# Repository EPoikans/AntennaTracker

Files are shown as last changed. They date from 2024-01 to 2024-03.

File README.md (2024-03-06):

<h1>Antenna Tracker</h1>

Realtime GPS based antenna tracking ground station for your drone.

Raspberry Pi 4B is used for HDMI capture of Walksnail OSD and incoming Mavlink message reading via SiK radio to obtain realtime drone coordinates.
GPS coordinates are read from each OSD frame with OpenCV KNN algortihm.
It is possible to use either only Mavlink message reading, only OSD frame capturing and analyzing and both at the same time.

A Raspbbery Pi Pico is connected to the main computer (Raspberry Pi 4B or any other) and recieves realtime servo positions to track the drone with an optional GPS module for ground station coordinates



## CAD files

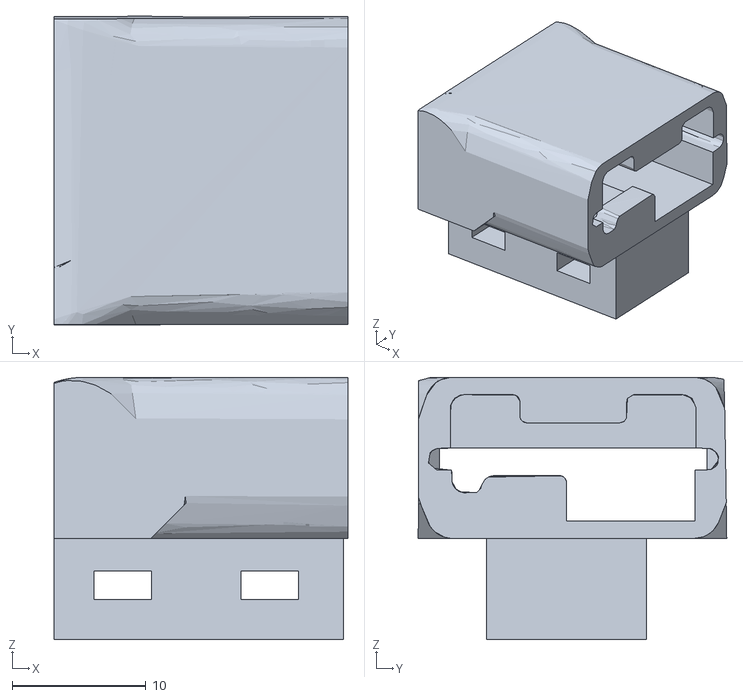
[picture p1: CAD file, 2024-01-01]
3D models/AntennaTracker_GPS_mount_TPU.stl
22.0 x 23.1 x 19.6

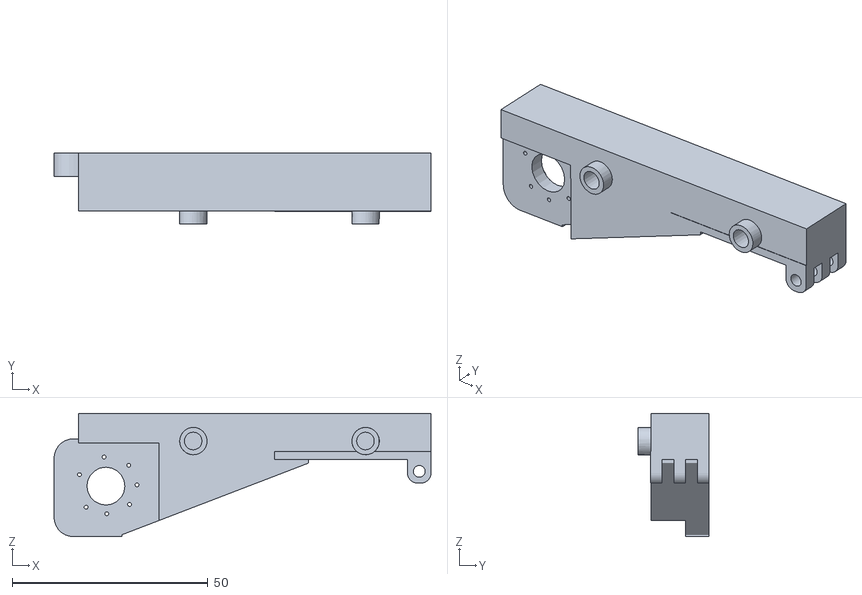
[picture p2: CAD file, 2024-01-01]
3D models/AntennaTracker_vertical_arm.stl
96.3 x 18.2 x 31.5

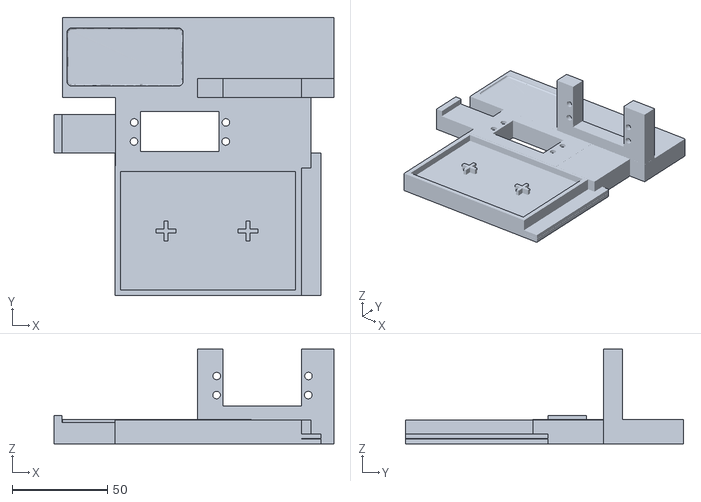
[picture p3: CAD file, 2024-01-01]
3D models/AntennaTracker_horizontal_plate.stl
146.9 x 145.9 x 49.7

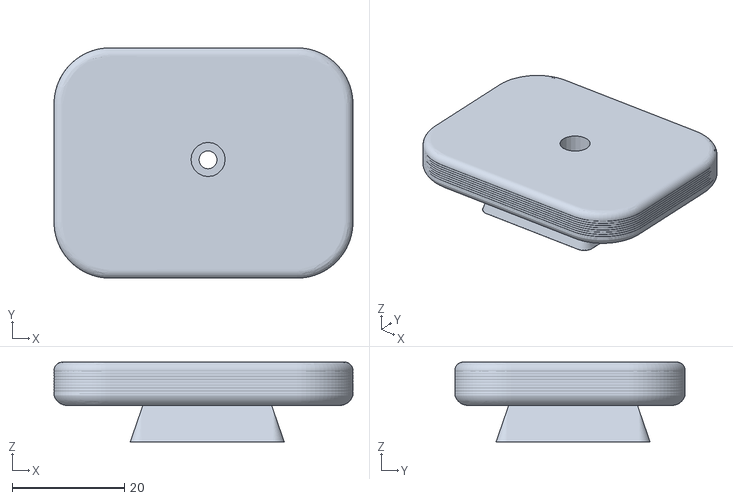
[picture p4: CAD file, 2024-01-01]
3D models/AntennaTracker_tripod_servo_connection.stl
53.4 x 41.1 x 14.2

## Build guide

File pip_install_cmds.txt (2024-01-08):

Windows cmds for required packages -
pip install pymavlink
pip install pyserial
pip install folium
pip install numpy
pip install opencv-python
pip install pillow

Raspberry pi commands for required packages - 
sudo pip install pymavlink --break-system-packages
sudo pip install pyserial --break-system-packages
sudo pip install folium --break-system-packages
sudo pip install numpy --break-system-packages
sudo pip install opencv-python --break-system-packages
sudo pip install pillow --break-system-packages

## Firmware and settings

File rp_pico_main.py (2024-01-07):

 
#Main script for the Raspberry Pi Pico. Does nothing on its own. 
#Communication over USB from serial_com.py file

from machine import Pin, I2C, UART, PWM
import sys
from time import sleep
import select
import utime
import ustruct
import math

compass_reg = { #QMC5883L magnetometer - https://datasheet.lcsc.com/lcsc/QST-QMC5883L-TR_C192585.pdf
    "MAGNETO_ADDRESS": 0xD,
    "MAGNETO_ID": 0xFF,
    "MAGNETO_ID_ADD": 0xD,
    "CONTROLREG1": 0x09,
    "CONTROLREG2": 0x0A,
    "DATAREG": 0x00,
    "DATACONV": 100.0 / 3000.0 #+/-8Gauss field range - 3000 LSb/Gauss -> 100LSb/uT
}

def initialize_pico(accelerometer = False):  
    global state, vertservo, horizonservo, i2c, uart_gps
    i2c = I2C(1, scl=Pin(19), sda=Pin(18), freq=400000) #I2C for magnetometer
    uart_gps = UART(0, baudrate=115200, tx=Pin(16), rx=Pin(17)) #UART for GPS
    
    if compass_reg["MAGNETO_ADDRESS"] in i2c.scan(): #Checks if magnetometer is connected
        i2c.writeto_mem(compass_reg["MAGNETO_ADDRESS"], compass_reg['CONTROLREG1'], bytes([0x1D]))
    vertservo = PWM(Pin(5)) #Vertical angle servo PWM pin
    horizonservo = PWM(Pin(6)) #Horizontal angle servo PWM pin
    vertservo.freq(50) #PWM frequency
    horizonservo.freq(50) #PWM frequency
    #Default servo states - 0deg vertical and horizontal with +/-115deg range
    vertservo.duty_u16(2000) #Vertical angle servo 2000-0deg, 5400 -90deg
    horizonservo.duty_u16(4900) # 4900 is center with roughly 115deg in each direction
    global vertservo, horizonservo, state
    state = True
    return state, vertservo, horizonservo

def readMagnetometer():
    global i2c
    try:
        data=i2c.readfrom_mem(compass_reg["MAGNETO_ADDRESS"], compass_reg["DATAREG"], 6)
        x = ((data[1] << 8) | data[0]) #Combines LSB and MSB in the correct order
        y = ((data[3] << 8) | data[2])
        z = ((data[5] << 8) | data[4])
        if x > 32767:
            x -= 65536
        if y > 32767:
            y -= 65536
        if z > 32767:
            z -= 65536
        x=(x)*compass_reg["DATACONV"] #Converts to uT
        #X axis offset due to servo motor magnetic field. Might need to be adjusted depending on location and servo
        x = x-136 
        y=(y)*compass_reg["DATACONV"] #Converts to uT
        #Y axis offset due to servo motor magnetic field. Might need to be adjusted depending on location and servo
        y = y - 50
        z=(z)*compass_reg["DATACONV"] #Converts to uT
        heading = math.atan2(y, x) #Calculates heading from magnetometer data
        heading = math.degrees(heading)
        day = 6
        declination_angle = math.sin(((-23.45)*math.pi/180) * math.cos(360/365 * (day + 10)))
        heading += declination_angle
        if heading < 0:
            heading += 360
        #print("Magnetic field in X: %.2f uT, Y: %.2f uT, Z: %.2f uT, Heading: %.2f°" % (x, y, z, heading)) #Debug print statement
        return str(heading)
    except:
        return ('err')

def setServoCycle (device, position): #Sets servo PWM cycle

    device.duty_u16(position)

    sleep(0.01)

def exec_cmd(command): #Processes incoming messages over USB to apropriate functions
    if(len(command)==0):
        return
    cmdparts = command.split() #Splits message into parts
    global vertservo, horizonservo, state
    fnname = cmdparts[0] #First part of message is the function name
    if(len(cmdparts) >=3 and cmdparts[0] == "setServoCycle"): #Checks if servo PWM cycle is being set
        servoname = cmdparts[1]
        pwmint = int(cmdparts[2])
    if fnname == "setServoCycle": #Sets servo PWM cycle
        if(servoname == "vert_servo"):
            setServoCycle(vertservo, pwmint)
            return("Set vert servo") #Returns a message to confirm the servo has been set
        elif(servoname == "horizon_servo"):
            setServoCycle(horizonservo, pwmint)
            return("Set horizontal servo") #Returns a message to confirm the servo has been set
    elif fnname == "initialize_pico": #Initializes the pico
        if(len(cmdparts)>=2 and cmdparts[1] == "accelerometer"):
            state, vertservo, horizonservo = initialize_pico(False) #True if use adxl345 - retired currently
        else:
            state, vertservo, horizonservo = initialize_pico()
        if(state):
            return("Initialized") #Returns a message to confirm the pico has been initialized
    elif fnname == "readMagnetometer": #Reads magnetometer data
        heading = readMagnetometer()
        return heading
    elif fnname == "pollGPS": #Requests GPS data from GPS module
        try:
            lat, lon = pollGPS()
            return lat, lon
        except:
            return 0, 0
    elif fnname == "checkGPSSat": #Requests active satellite count from GPS module
        sat_count = checkGPSSat()
        return sat_count
    elif fnname == "PortCheck": #PortCheck is sent to every possible serial port to find the correct one which the pico is connected to
        portconfirm = "RPPico" #Returns a message to confirm the pico has been found
        return str(portconfirm)

#GPS module chip - M10 using NMEA 0183 messages
"""
NMEA 0183 messages

Talker IDs -
BD or GB - Beidou
GA - Galileo
GP - GPS
GL - GLONASS
GN - Combined talkers

$(Talker ID) + GGA  - Global Positioning System Fixed Data
$(Talker ID) + GLL - Geographic Position-- Latitude and Longitude 
$(Talker ID) + GSA - GNSS Dilution of Precision and active satellites 
$(Talker ID) + GSV - GNSS satellites in view 
$(Talker ID) + RMC - Recommended minimum specific GPS data 
$(Talker ID) + VTG - Course over ground and ground speed 

<CR><LF> or \r\n - end of message
$ - begining of message

$GNGSA - active sattelite count
$GNGLL - lat and lon 
"""


def pollGPS():
    global uart_gps
    lat, lon, lat_deg, lat_min, lon_deg, lon_min = 0,0,0,0,0,0
    timeoutvar = 0
    while True:
        gps_data = uart_gps.readline() #Reads GPS data from UART
        if(gps_data != 'None'): #Checks if data is None or a NMEA message
            try:    
                gps_fields = gps_data.decode().split(',') #NMEA messages are split with ,
                if(gps_fields[0] == '$GNGLL' and gps_fields[6] == 'A'): #Latitude and Longitude with active satellites
                    lat_deg = gps_fields[1][:2]
                    lat_min = gps_fields[1][2:]
                    lon_deg = gps_fields[3][:3]
                    lon_min = gps_fields[3][3:]
                    lat = round((float(lat_deg) + (float(lat_min)/60)), 7) #Converts latitude and longitude from minutes to decimal
                    lon = round((float(lon_deg) + (float(lon_min)/60)), 7)
                    return lat, lon
                elif(gps_fields[0] == '$GNGGA' and int(gps_fields[7])>=6): #Global Positioning System Fix Data for all gps systems with 6 or more active satellites
                    lat_deg = gps_fields[2][:2]
                    lat_min = gps_fields[2][2:]
                    lon_deg = gps_fields[4][:3]
                    lon_min = gps_fields[4][3:]
                    lat = round((float(lat_deg) + (float(lat_min)/60)), 7) #Converts latitude and longitude from minutes to decimal
                    lon = round((float(lon_deg) + (float(lon_min)/60)), 7)
                    return lat, lon
            except:
                timeoutvar +=1
                if(timeoutvar >= 10000): #Timeout
                    break
                else:
                    pass
                
            
def checkGPSSat():
    global uart_gps
    sat_count = 0
    timeoutvar = 0
    while True:
        gps_data = uart_gps.readline() #Reads GPS data from UART
        if(gps_data != 'None'): #Checks if data is None or a NMEA message
            try:
                gps_fields = gps_data.decode().split(',') #NMEA messages are split with ,
                if(gps_fields[0] == '$GNGSA' and gps_fields[1] == 'A' and int(gps_fields[2]) >= 3): #Global Positioning System Dilution of Precision and active satellites
                    i = 1
                    while True:
                        if(gps_fields[2+i] != ''): #Checks each field for satelite number and adds to sattelite count. The message contains from the 3rd field onwards active satellite number
                            sat_count += 1
                        else:
                            break
                        i+=1
                    return sat_count
            except:
                timeoutvar +=1 #Timeout
                if(timeoutvar >= 50000):
                    break
                else:
                    pass
    return sat_count #Returns active satellite count or 0 if no satellites are found

poll_obj = select.poll()
poll_obj.register(sys.stdin, 1)
sleep(4) #Waits 4 seconds before centering servos after plugging in power to the pico
initialize_pico() #Calls initialize_pico function that initializes I2C, UART and PWM
sleep(2) #Waits 2 seconds before listening for serial incoming messages
while True:
    global state, vertservo, horizonservo
    if poll_obj.poll(20):     
        reciev = sys.stdin.readline().strip() #Reads incoming message
        if(not reciev):
            continue
        else:
            if(reciev == 'exit'):
                sys.exit()
            res = exec_cmd(reciev) #Calls exec_cmd function to process incoming message
            if res is not None:
                print(str(res)) #Print statements are picked up as response by serial_com.py
            else:
                print('No response') 

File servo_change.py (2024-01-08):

import serial_com
import initialize_data

global pwm_current_estimate, pwm_angle_current_estimate
pwm_current_estimate = 4900 #Default center value

pwm_angle_current_estimate = 2000 #Default 0deg value

def headingchangeFn(heading, endheading_from_home, accelerometer, zeroHeading): #4900 - mid, 1200 -115deg, 8600 - +115deg
	global pwm_current_estimate 
	
	if(zeroHeading >=245): #Handles the overflow of heading values going 360 -> 0 deg
		headingOverflow = abs(zeroHeading+115 - 360)
		if(endheading_from_home >= 0 and endheading_from_home <= headingOverflow):
			endheading_from_home+=360
	if(zeroHeading <=115): #Handles the overflow of heading values going 0 -> 360 deg
		headingOverflow = abs(zeroHeading-115+360)
		if(endheading_from_home<=360 and endheading_from_home >= headingOverflow):
			endheading_from_home-=360
	headingdiff = (int(zeroHeading) - int(endheading_from_home))*(-1) #Calculates the difference between the home heading and desired heading
	if(initialize_data.debug): #Debug print
		headingOverflow = locals().get('headingOverflow', 0)
		print(str(headingdiff) + '- headingdiff ' + str(endheading_from_home) + '- endheading_from_home ' + str(zeroHeading) + ' - zeroHeading ' + str(headingOverflow) + ' - headingOverflow')
	if(abs(headingdiff)>=115 and abs(headingdiff)<=190): #If the absolute heading difference from home is above 115deg then it will stay at the max of the correct side
		if(headingdiff>0):
			pwm_freq = 1200
			if(initialize_data.debug): #Debug print
				print(str(pwm_current_estimate) + ' current ' + str(pwm_freq) + ' pwm 1')
			serial_com.setHorizontalServo(pwm_freq, pwm_current_estimate) #Calls serial command to send the PWM value to the servo
			pwm_current_estimate = pwm_freq
		elif(headingdiff<=0):
			pwm_freq = 8600
			if(initialize_data.debug): #Debug print
				print(str(pwm_current_estimate) + ' current ' + str(pwm_freq) + ' pwm 2')
			serial_com.setHorizontalServo(pwm_freq, pwm_current_estimate) #Calls serial command to send the PWM value to the servo
			pwm_current_estimate = pwm_freq
	elif(abs(headingdiff)>=190): #If the absolute heading difference from home is above 190deg then it will stay at the max of the opposite side
		if(headingdiff<0):
			pwm_freq = 1200
			if(initialize_data.debug): #Debug print
				print(str(pwm_current_estimate) + ' current ' + str(pwm_freq) + ' pwm 3')
			serial_com.setHorizontalServo(pwm_freq, pwm_current_estimate) #Calls serial command to send the PWM value to the servo
			pwm_current_estimate = pwm_freq
		elif(headingdiff>=0):
			pwm_freq = 8600
			if(initialize_data.debug): #Debug print
				print(str(pwm_current_estimate) + ' current ' + str(pwm_freq) + ' pwm 4')
			serial_com.setHorizontalServo(pwm_freq, pwm_current_estimate) #Calls serial command to send the PWM value to the servo
			pwm_current_estimate = pwm_freq
	elif(headingdiff>0): #Establishes the correct direction of movement
		pwm_freq = 4900 - int(3700/115*abs(headingdiff)) #Calculates the PWM offset from center which is home value if the absolute heading difference is under 115deg
		if(initialize_data.debug): #Debug print
			print(str(pwm_current_estimate) + ' current ' + str(pwm_freq) + ' pwm 5')
		serial_com.setHorizontalServo(pwm_freq, pwm_current_estimate) #Calls serial command to send the PWM value to the servo
		pwm_current_estimate = pwm_freq
	elif(headingdiff<=0):
		pwm_freq = 4900 + int(3700/115*abs(headingdiff)) #Calculates the PWM offset from center which is home value if the absolute heading difference is under 115deg
		if(initialize_data.debug): #Debug print
			print(str(pwm_current_estimate) + ' current ' + str(pwm_freq) + ' pwm 6')
		serial_com.setHorizontalServo(pwm_freq, pwm_current_estimate) #Calls serial command to send the PWM value to the servo
		pwm_current_estimate = pwm_freq
	new_heading = endheading_from_home
	return new_heading

def anglechangeFn(angle, end_angle, accelerometer):
	global pwm_angle_current_estimate
	if(end_angle <= 90):
		pwm_freq = 2000 + int(3400/90*end_angle) #2000 - 0degrees and 5400 is 90deg vertical angle
		if(initialize_data.debug): #Debug print
			print(str(pwm_current_estimate) + ' - current ' + str(pwm_freq) + ' - pwm')
		serial_com.setVerticalServo(pwm_freq, pwm_angle_current_estimate) #Calls serial command to send the PWM value to the servo
		pwm_angle_current_estimate = pwm_freq
	else:
		pwm_freq = 5400
		serial_com.setVerticalServo(pwm_freq, pwm_angle_current_estimate) #Calls serial command to send the PWM value to the servo
		pwm_angle_current_estimate = pwm_freq
	new_angle = end_angle
	return new_angle

def headingChangeFailsafe(heading, homeheading): #Failsafe function calling sharp movements in rough area of last known heading
	headingdiff = int(homeheading) - int(heading)
	if(abs(headingdiff)>=100):
		if(headingdiff<0):
			pwm_freq = 1250
			serial_com.setHorizontalServo(pwm_freq, pwm_freq)
		elif(headingdiff>=0):
			pwm_freq = 8750
			serial_com.setHorizontalServo(pwm_freq, pwm_freq)
	elif(headingdiff<0):
		pwm_freq = 5000 - int((3750/100)*abs(headingdiff))
		serial_com.setHorizontalServo(pwm_freq, pwm_freq)
	elif(headingdiff>=0):
		pwm_freq = 5000 + int((3750/100)*abs(headingdiff))
		serial_com.setHorizontalServo(pwm_freq, pwm_freq)
	return

def angleChangeFailsafe(angle): #Failsafe function calling sharp movements in rough area of last known angle
	if(angle <= 90):
			pwm_freq = 2000 + int(3400/90*angle) #2000 - 0degrees
			serial_com.setVerticalServo(pwm_freq, pwm_freq)
	else:
		pwm_freq = 5400
		serial_com.setVerticalServo(pwm_freq, pwm_freq)
	return

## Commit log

2023-12-24 Sample video GUI feature
2023-12-25 Mavlink sample window
2024-01-01 Gradual servo freq change
2024-01-01 Added used 3D models
    [AntennaTracker_GPS_mount_TPU.stl, AntennaTracker_horizontal_plate.stl, AntennaTracker_tripod_servo_connection.stl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]
2024-01-02 GPS functionality on Pico and mavlink fix
    [initialize_data.py, rp_pico_main.py]
2024-01-02 GPS ground station select
2024-01-03 Fixed magnetometer + Raspi fixes
    [gps_calculation.py, initialize_data.py, rp_pico_main.py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]
2024-01-04 Minor fixes + UI upgrade
    [gps_calculation.py, serial_com.py, ui_window.py]
2024-01-07 Servo cmd fixes + debug variables
    [Numberlearn.py, gps_calculation.py, img_processing.py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]
